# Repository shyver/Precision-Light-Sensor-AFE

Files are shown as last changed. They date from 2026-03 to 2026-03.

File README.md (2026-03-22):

# Precision Photodiode Analog Front-End (AFE)





## 📌 Project Overview
This repository contains the hardware design files and LTspice simulations for a high-precision, low-noise Photodiode Signal Conditioning Board. 

Designed as a modular Analog Front-End (AFE), this board converts ambient light intensity into a clean, stable analog voltage (0–3.3V) suitable for direct sampling by microcontrollers (e.g., ESP32, STM32, Arduino) using a Transimpedance Amplifier (TIA) architecture.

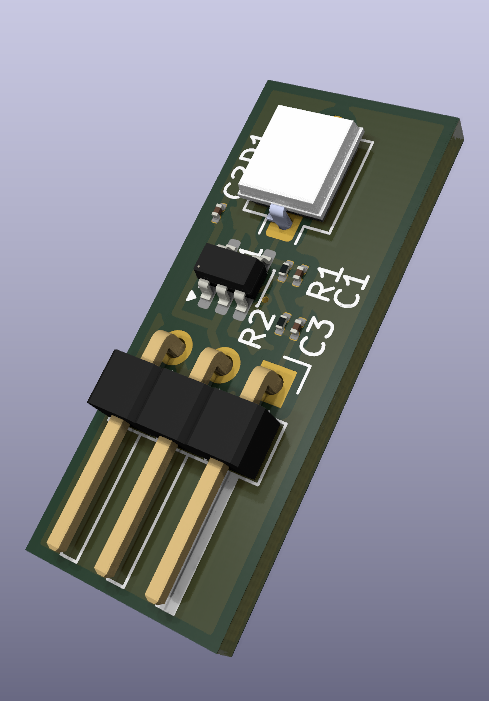
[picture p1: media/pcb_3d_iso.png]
pcb_3d


## ✨ Key Features
* **Transimpedance Amplifier (TIA):** Converts microscopic photodiode currents into a measurable voltage with a calculated gain of 68kΩ.
* **Optimized Stability:** Includes a precisely calculated 20pF feedback capacitor to compensate for the photodiode's junction capacitance and prevent op-amp oscillation.
* **ADC Shock Absorption:** Features an RC low-pass output filter (100Ω + 10nF) to eliminate high-frequency noise and stabilize the signal against MCU ADC sampling glitches.
* **Ultra-Low Leakage:** Utilizes the MCP6001 CMOS operational amplifier with an input bias current of just 1pA to ensure the sensor signal is not degraded.
* **Plug-and-Play Interface:** Standard 3-pin connector (VCC, GND, OUT) for seamless integration into embedded systems.

## 🛠️ Hardware Specifications
| Component | Part / Value | Description |
| :--- | :--- | :--- |
| **Photodiode** | BPW34S | Broadband silicon photodiode. High photocurrent (~50µA at 1000 Lux), low dark current (2nA). |
| **Op-Amp** | MCP6001 | Single-supply, Rail-to-Rail Output (RRO), CMOS input (1pA Bias Current). |
| **Gain Resistor ($R_f$)** | 68 kΩ | Sets the voltage output range (Max 3.3V at ~50µA input). |
| **Compensation Cap ($C_f$)**| 20 pF | Prevents ringing/oscillation caused by the photodiode's 72pF junction capacitance. |
| **Supply Voltage** | 3.3V | Single-supply operation. Decoupled via 0.1µF capacitor. |

## 📐 Circuit Architecture & Theory

### 1. The Sensor Stage
The BPW34S photodiode is operated in photovoltaic/zero-bias mode. This configuration minimizes dark current leakage, resulting in the highest possible precision and lowest noise floor for ambient light detection.

### 2. The Transimpedance Stage
The core of the board is the TIA. The gain is set by the feedback resistor ($R_f$). 
Using Ohm's Law ($V = I \times R$), a peak ambient room light producing $~50 \mu A$ of current is multiplied by $68 k\Omega$ to produce a $~3.4V$ output, perfectly utilizing the 3.3V ADC range of modern microcontrollers.

### 3. Stability & Compensation
Photodiodes with large active areas (like the BPW34S) have high junction capacitance ($C_j \approx 72pF$). Without compensation, this capacitance creates a phase shift in the op-amp's feedback loop, causing severe ringing and instability. A 20pF feedback capacitor ($C_f$) was mathematically calculated and verified via SPICE simulation to critically damp the circuit and provide a smooth transient response.

## 📂 Repository Structure
* `/kicad` - KiCad 9.0 project files (Schematic, PCB Layout, Footprints).
* `/Simulation` - LTspice `.asc` files demonstrating Transient and AC (Frequency Response) analysis.
* `/Docs` - Datasheets for the BPW34S and MCP6001.
* `/Manufacturing` - Gerber files, Drill files, and BOM ready for PCB manufacturing (e.g., JLCPCB).
*  `/Media` - Project media and screenshots.

## 🚀 Getting Started
1. Clone this repository: `git clone https://github.com/shyver/Precision-Light-Sensor-AFE.git`
2. Open the `.pro` or `.kicad_pro` file in **KiCad**.
3. To view the simulations, open the `.asc` files located in the `/Simulation` folder using **LTspice**.

## 📝 License
This project is open-source and available under the [MIT License](LICENSE).

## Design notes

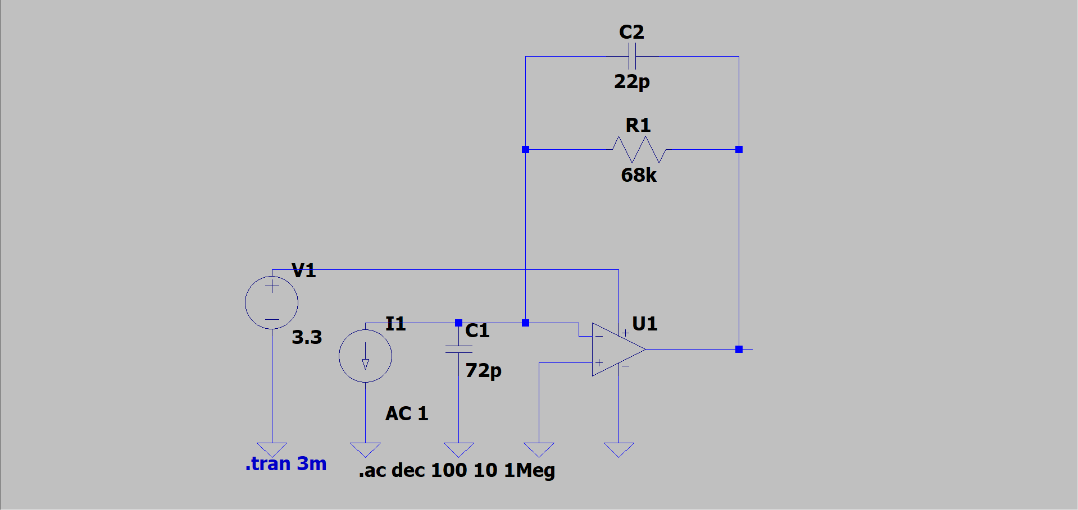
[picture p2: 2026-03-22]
media/final LTspice schematic.png

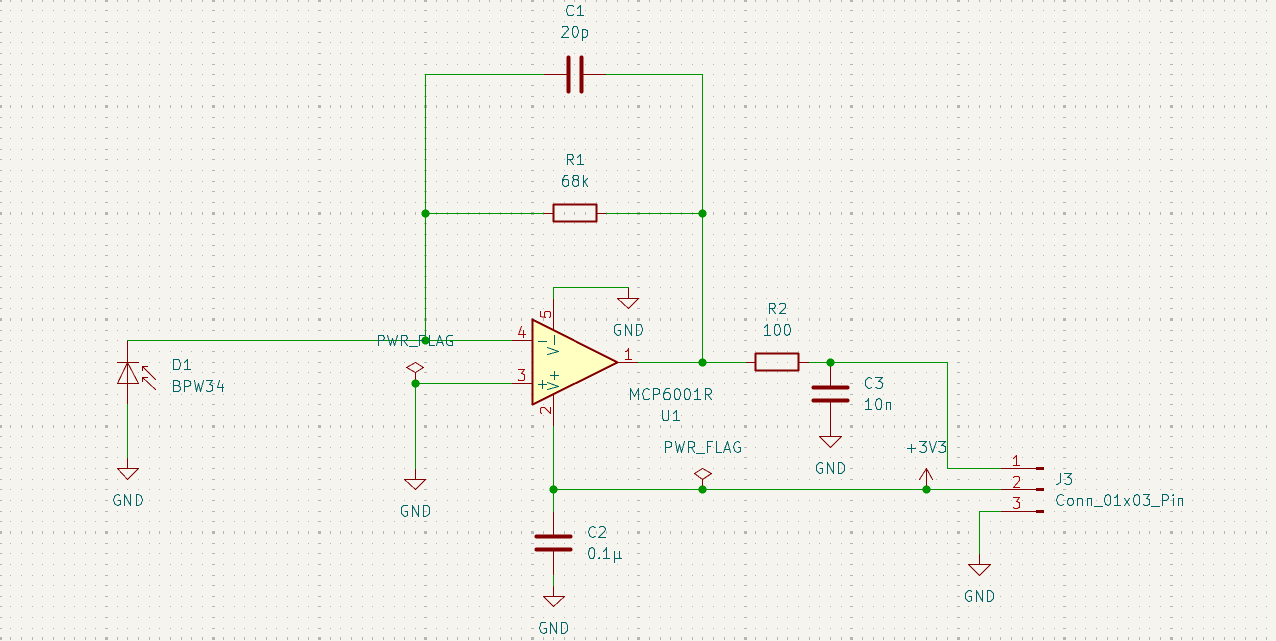
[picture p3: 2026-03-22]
media/kicad schematic.png

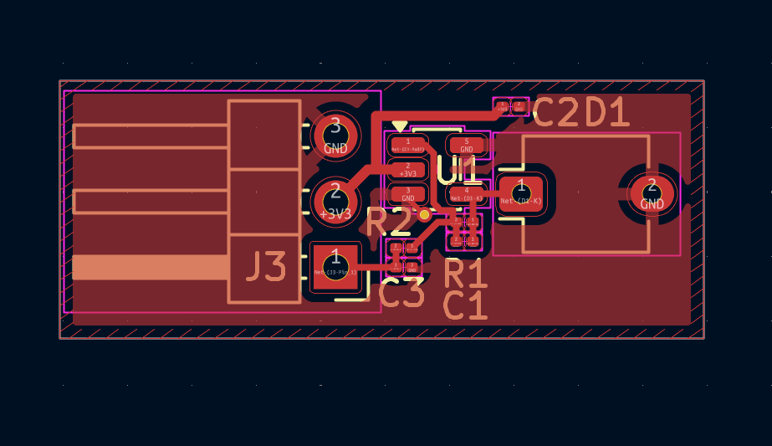
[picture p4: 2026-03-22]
media/pcb_front.png

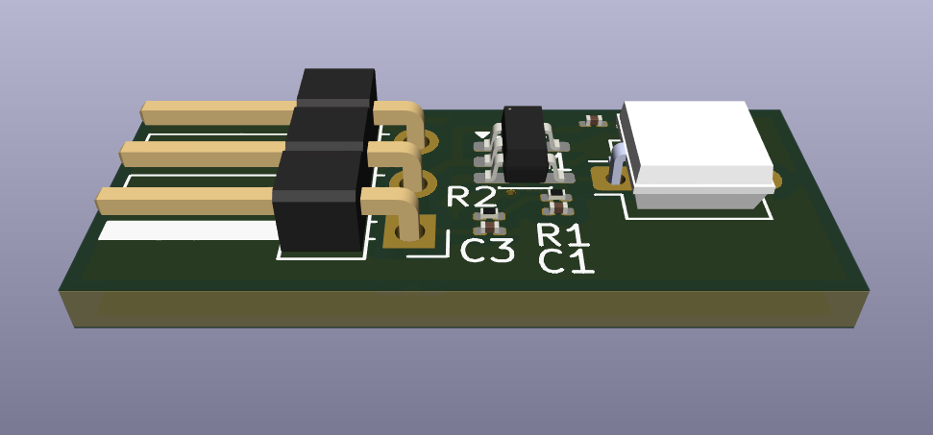
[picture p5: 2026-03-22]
media/pcb_3d_angle.png

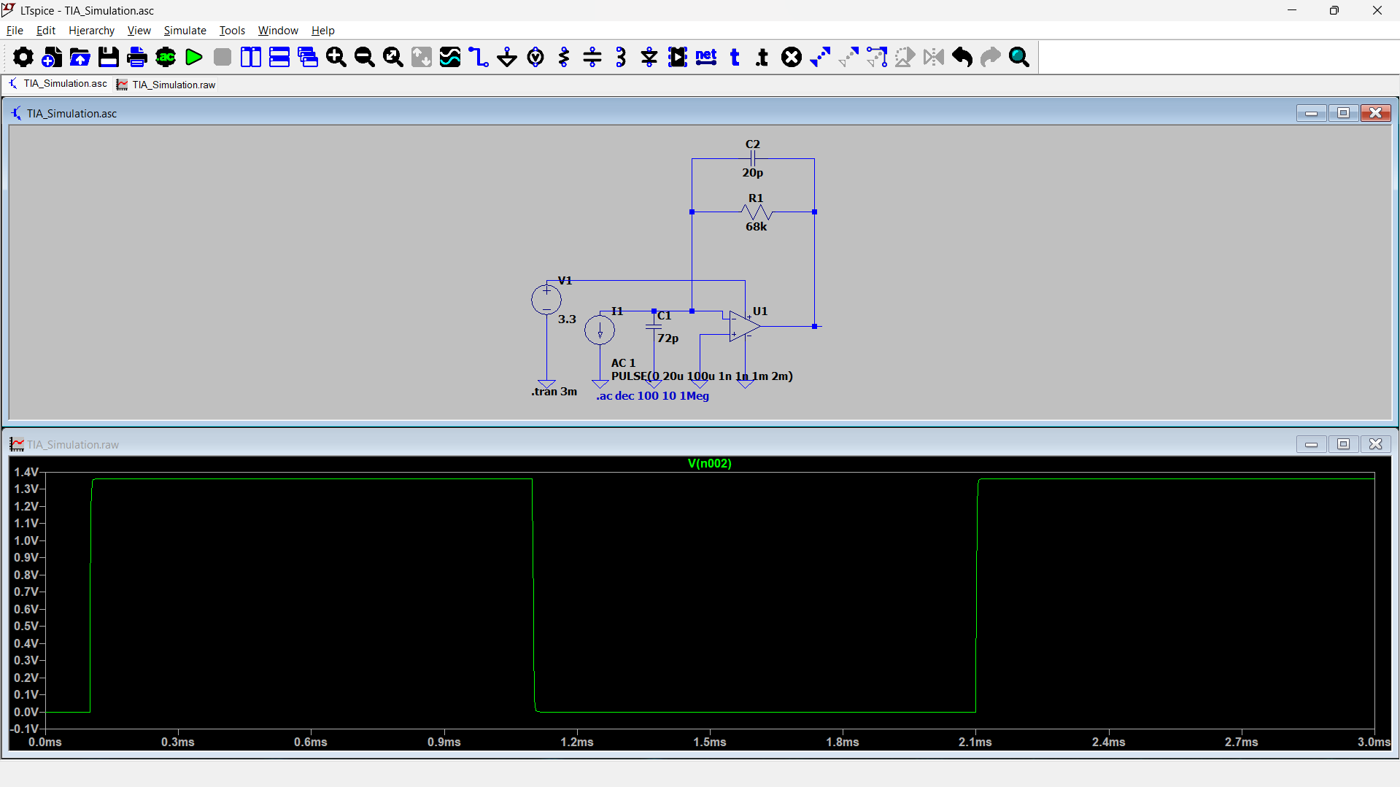
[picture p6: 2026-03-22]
media/transient response (compensated).png

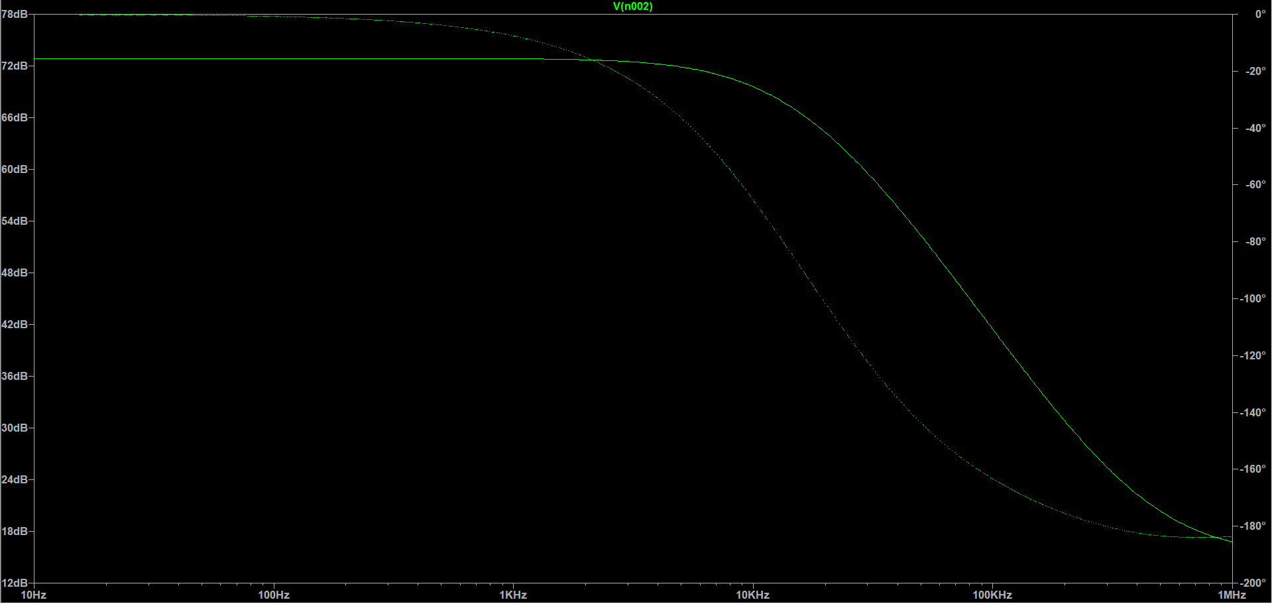
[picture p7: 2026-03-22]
media/AC freduency response (baude plot).png

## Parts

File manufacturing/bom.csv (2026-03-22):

Reference | Qty | Value | DNP | Exclude from BOM | Exclude from Board | Footprint | Datasheet
C1 | 1 | 20p |  |  |  | Capacitor_SMD:C_0201_0603Metric | ~
C2 | 1 | 0.1µ |  |  |  | Capacitor_SMD:C_0201_0603Metric | ~
C3 | 1 | 10n |  |  |  | Capacitor_SMD:C_0201_0603Metric | ~
D1 | 1 | BPW34 |  |  |  | OptoDevice:Osram_DIL2_4.3x4.65mm_P5.08mm | http://www.vishay.com/docs/81521/bpw34.pdf
J3 | 1 | Conn_01x03_Pin |  |  |  | Connector_PinHeader_2.54mm:PinHeader_1x03_P2.54mm_Horizontal | ~
R1 | 1 | 68k |  |  |  | Resistor_SMD:R_0201_0603Metric | ~
R2 | 1 | 100 |  |  |  | Resistor_SMD:R_0201_0603Metric | ~
U1 | 1 | MCP6001R |  |  |  | Package_TO_SOT_SMD:SOT-23-5 | https://ww1.microchip.com/downloads/en/DeviceDoc/MCP6001-1R-1U-2-4-1-MHz-Low-Power-Op-Amp-DS20001733L.pdf

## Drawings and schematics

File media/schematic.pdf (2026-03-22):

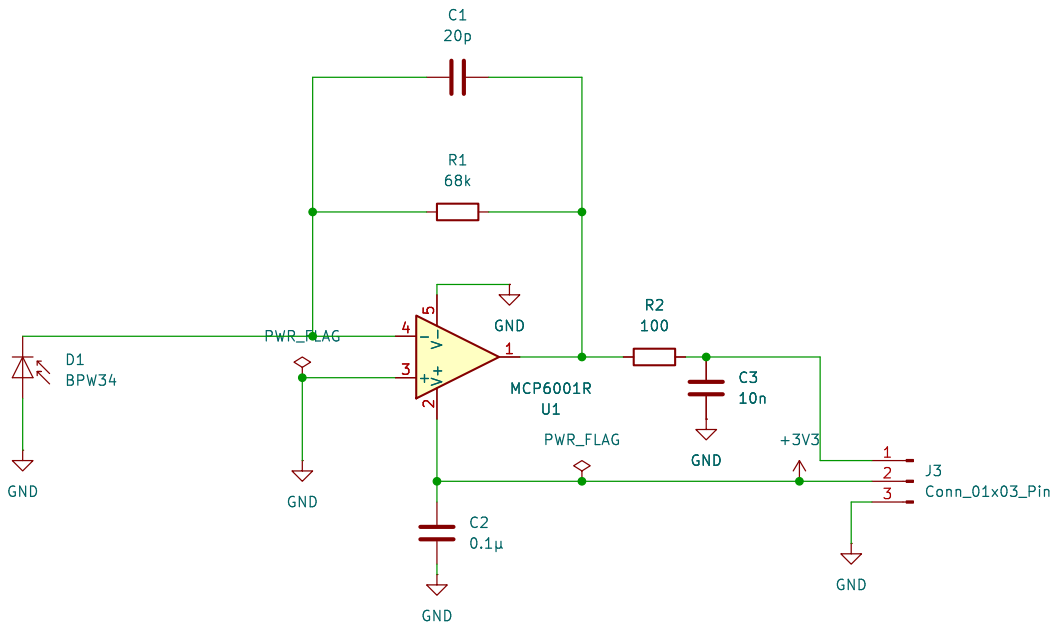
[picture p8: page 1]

Id: 1/1 Title: Precision Light Sensor AFE

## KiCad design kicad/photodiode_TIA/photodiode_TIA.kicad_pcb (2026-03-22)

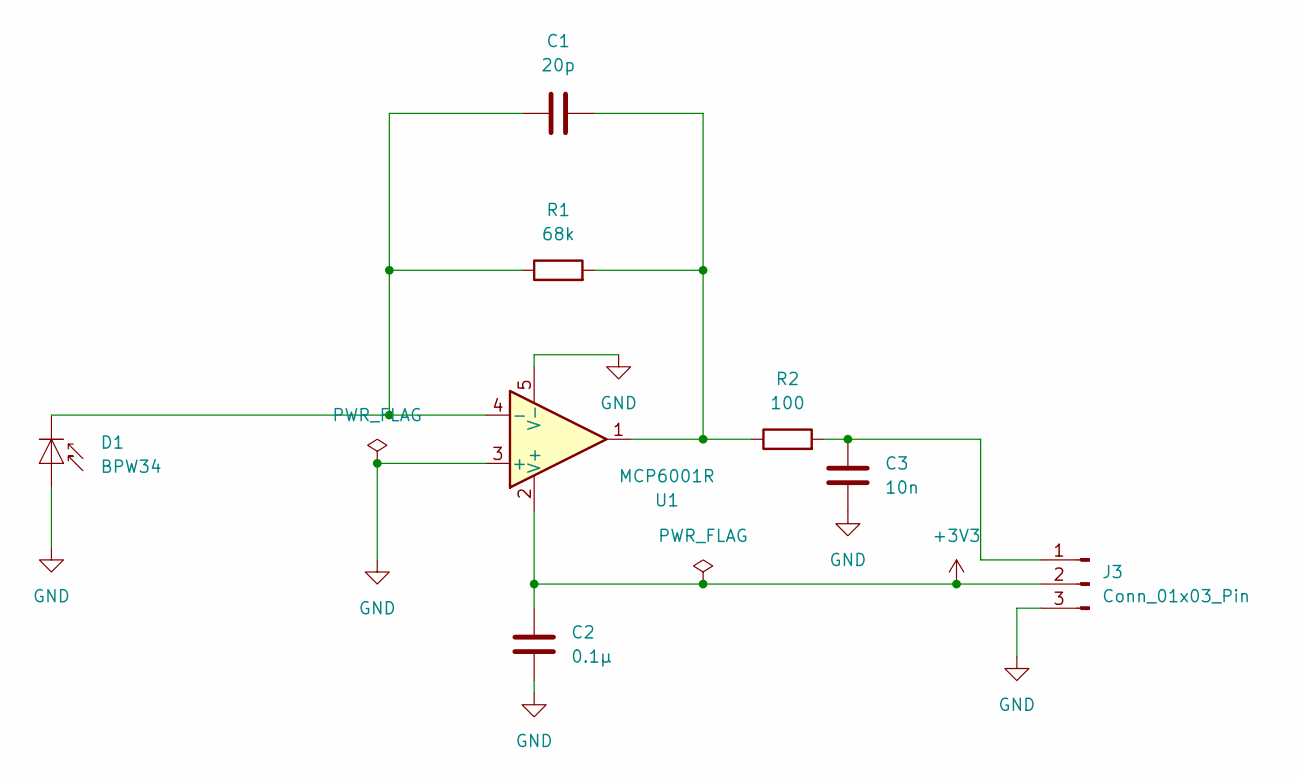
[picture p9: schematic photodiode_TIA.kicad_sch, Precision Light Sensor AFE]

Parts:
C1: 20p; C_0201_0603Metric
C2: 0.1µ; C_0201_0603Metric
C3: 10n; C_0201_0603Metric
D1: BPW34; Osram_DIL2_4.3x4.65mm_P5.08mm
J3: Conn_01x03_Pin; PinHeader_1x03_P2.54mm_Horizontal
R1: 68k; R_0201_0603Metric
R2: 100; R_0201_0603Metric
U1: MCP6001R; SOT-23-5

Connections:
+3V3: C2.1, J3.2, U1.2 (V+)
GND: C2.2, C3.2, D1.2 (A), J3.3, U1.3 (+), U1.5 (V-)
unnamed: C1.2, R1.2, R2.1, U1.1
unnamed: C1.1, D1.1 (K), R1.1, U1.4 (-)
unnamed: C3.1, J3.1, R2.2

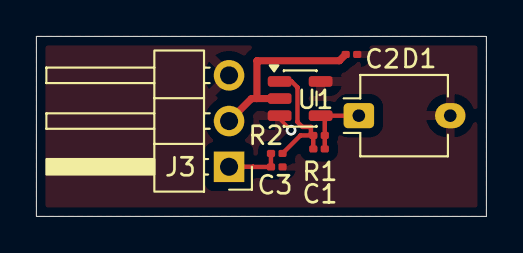
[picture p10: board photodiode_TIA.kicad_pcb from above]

Board: 2 copper layers, 25.0 x 10.0 mm, 8 parts (0 on the bottom side), 5 nets.

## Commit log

2026-03-22 first commit, schematic ready
    [photodiode_TIA.kicad_pcb, photodiode_TIA.kicad_sch]
2026-03-22 complete layout
    [photodiode_TIA.kicad_pcb]
2026-03-22 added media
    [photodiode_TIA.kicad_pcb, photodiode_TIA.kicad_sch]
2026-03-22 added manufacturing files
    [bom.csv, photodiode_TIA.kicad_pcb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]
2026-03-22 Update KiCad version in README
2026-03-22 Add 3D PCB screenshot to README
    Updated README to include a 3D PCB screenshot.

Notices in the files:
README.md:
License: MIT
